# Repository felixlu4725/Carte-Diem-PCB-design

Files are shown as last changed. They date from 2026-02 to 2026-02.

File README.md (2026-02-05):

# Carte Diem — PCB

This directory contains the **custom ESP32-S3-based PCB** designed for the Carte Diem smart shopping cart system.  
The board serves as the central embedded controller, interfacing with all on-cart sensors, peripherals, and the Raspberry Pi.

---

## Overview

The PCB is responsible for:
- Real-time sensor acquisition
- Item verification and cart state monitoring
- Power distribution and regulation
- BLE communication with the Raspberry Pi

It was designed to support **all-day operation**, modular peripherals, and reliable performance in a noisy retail environment.

---

## Manufractured PCB


## Key Features

- **ESP32-S3 MCU**
  - Runs FreeRTOS
  - Handles sensing, control, and BLE communication

- **Peripheral Interfaces**
  - UART: barcode scanner, item RFID, cart-tracking RFID
  - SPI: payment RFID module
  - I²C: IMU, proximity sensor
  - GPIO + ADC: load cells (via HX711)

- **Power Architecture**
  - 12 V input (external battery)
  - On-board buck and LDO regulation
  - Supports 12 V, 9 V, 5 V, 3.3 V, and 1.8 V rails

- **Connectivity**
  - BLE for bidirectional communication with Raspberry Pi
  - Dedicated connectors for modular sensor attachment

---

## Design Notes

- EMI mitigation was required due to proximity of RFID modules and load cells  
- Power paths were designed conservatively to support peak current draw  
- The board went through multiple revisions to resolve rail shorting and voltage tolerance issues  

---

## Schematic

### Top level


### Power Distribution


### Integrated IMU


### Routing


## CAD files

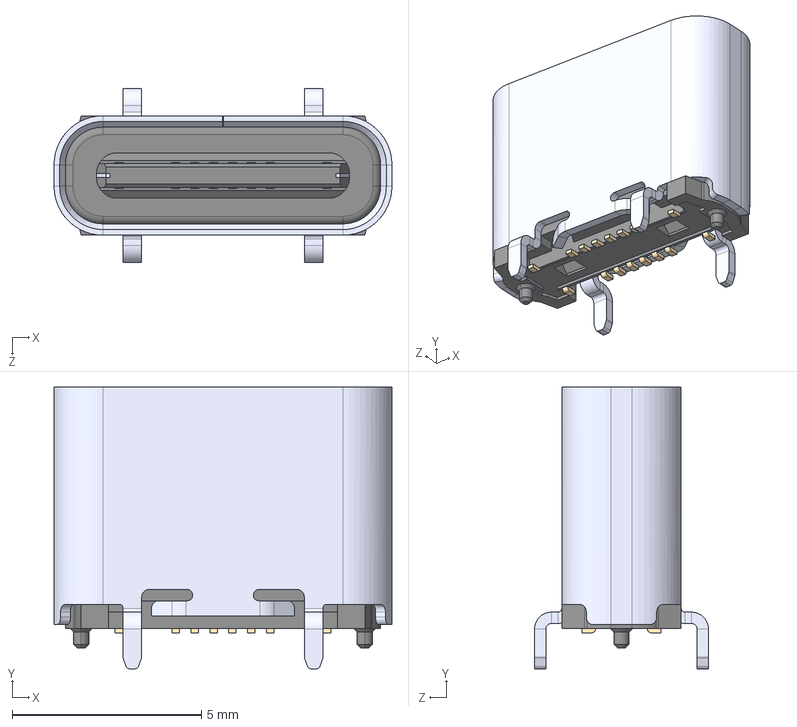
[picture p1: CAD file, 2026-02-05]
Custom_Library/StepFiles/USB4120-03-C_REVA.step
8.94 x 7.45 x 4.60 mm

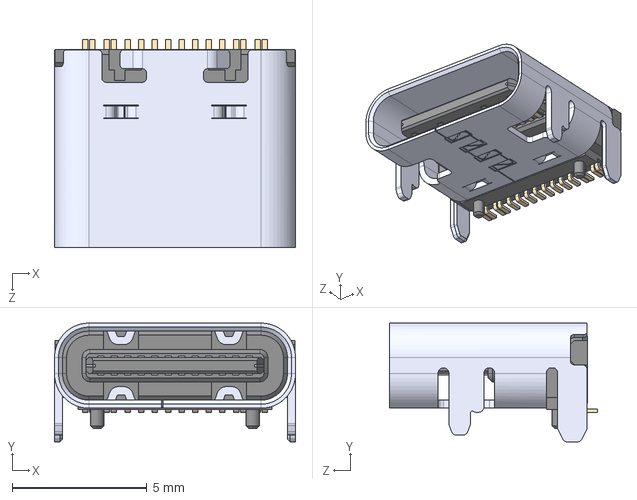
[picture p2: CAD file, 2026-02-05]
Custom_Library/StepFiles/USB4105GFA.step
8.94 x 4.41 x 7.71 mm

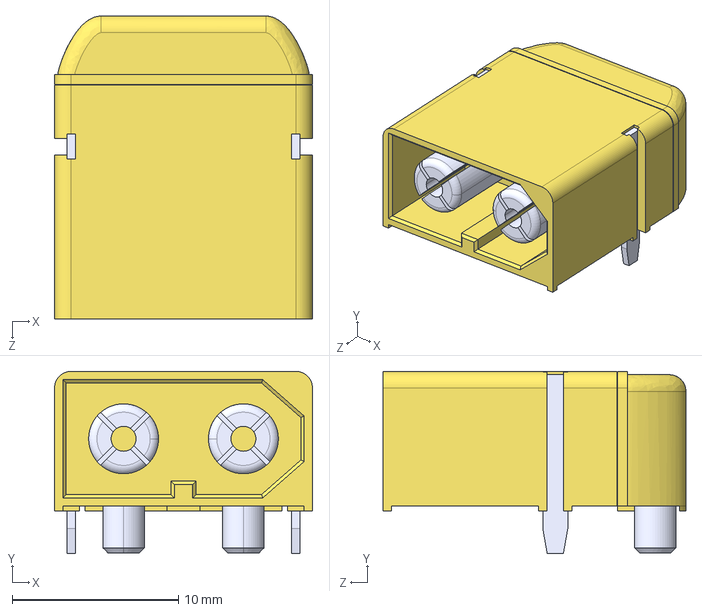
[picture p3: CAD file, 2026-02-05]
Custom_Library/StepFiles/XT60PW-M.step
15.5 x 10.9 x 18.2 mm

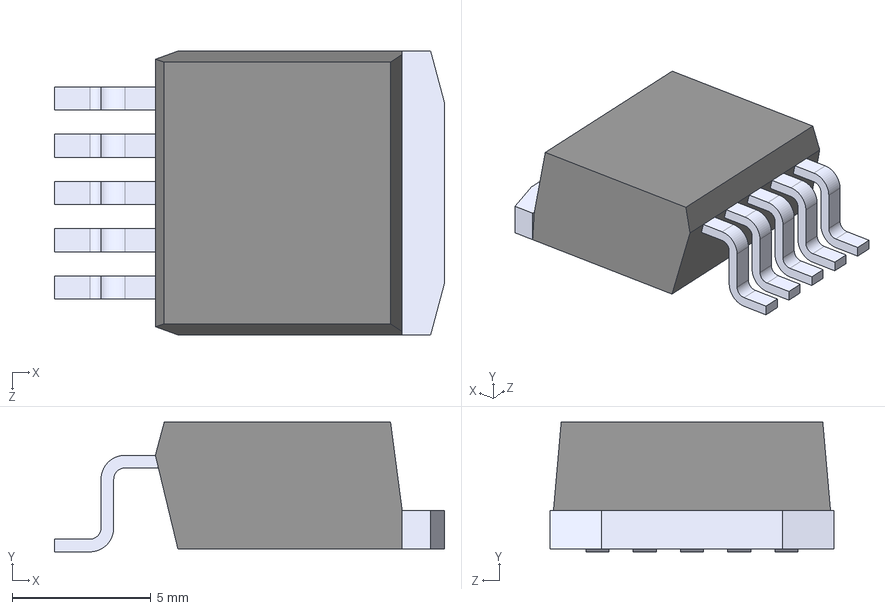
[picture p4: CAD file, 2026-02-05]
Custom_Library/StepFiles/LT1764AEQPBF.step
14.0 x 4.67 x 10.2 mm

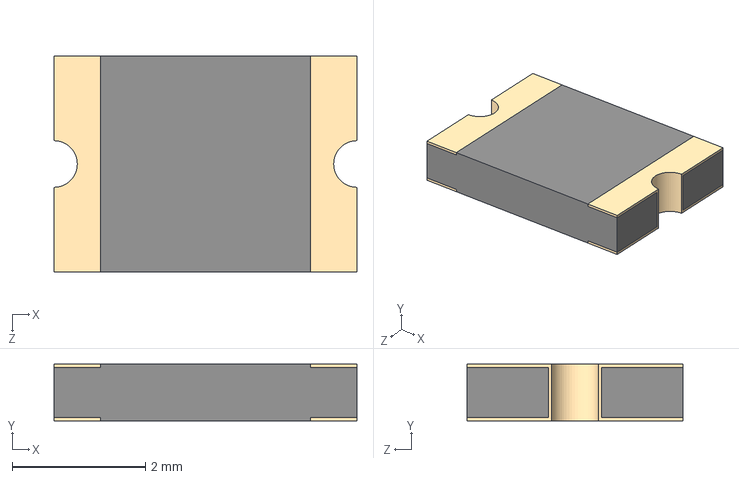
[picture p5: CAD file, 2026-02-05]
Custom_Library/StepFiles/MF-MSMF010-2.step
4.55 x 0.85 x 3.24 mm

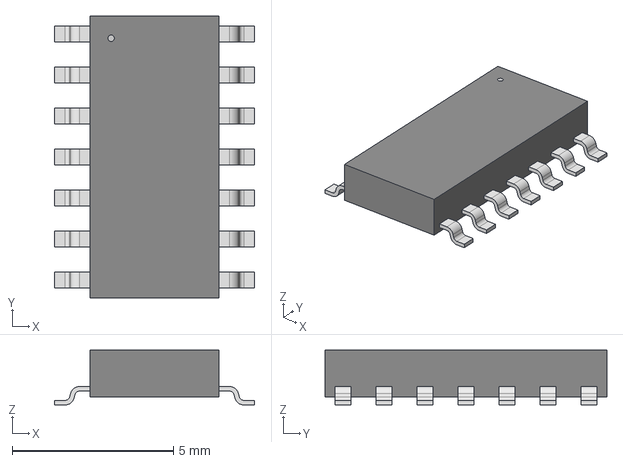
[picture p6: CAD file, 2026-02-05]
Custom_Library/StepFiles/SO14_DIO.step
6.20 x 8.74 x 1.70 mm

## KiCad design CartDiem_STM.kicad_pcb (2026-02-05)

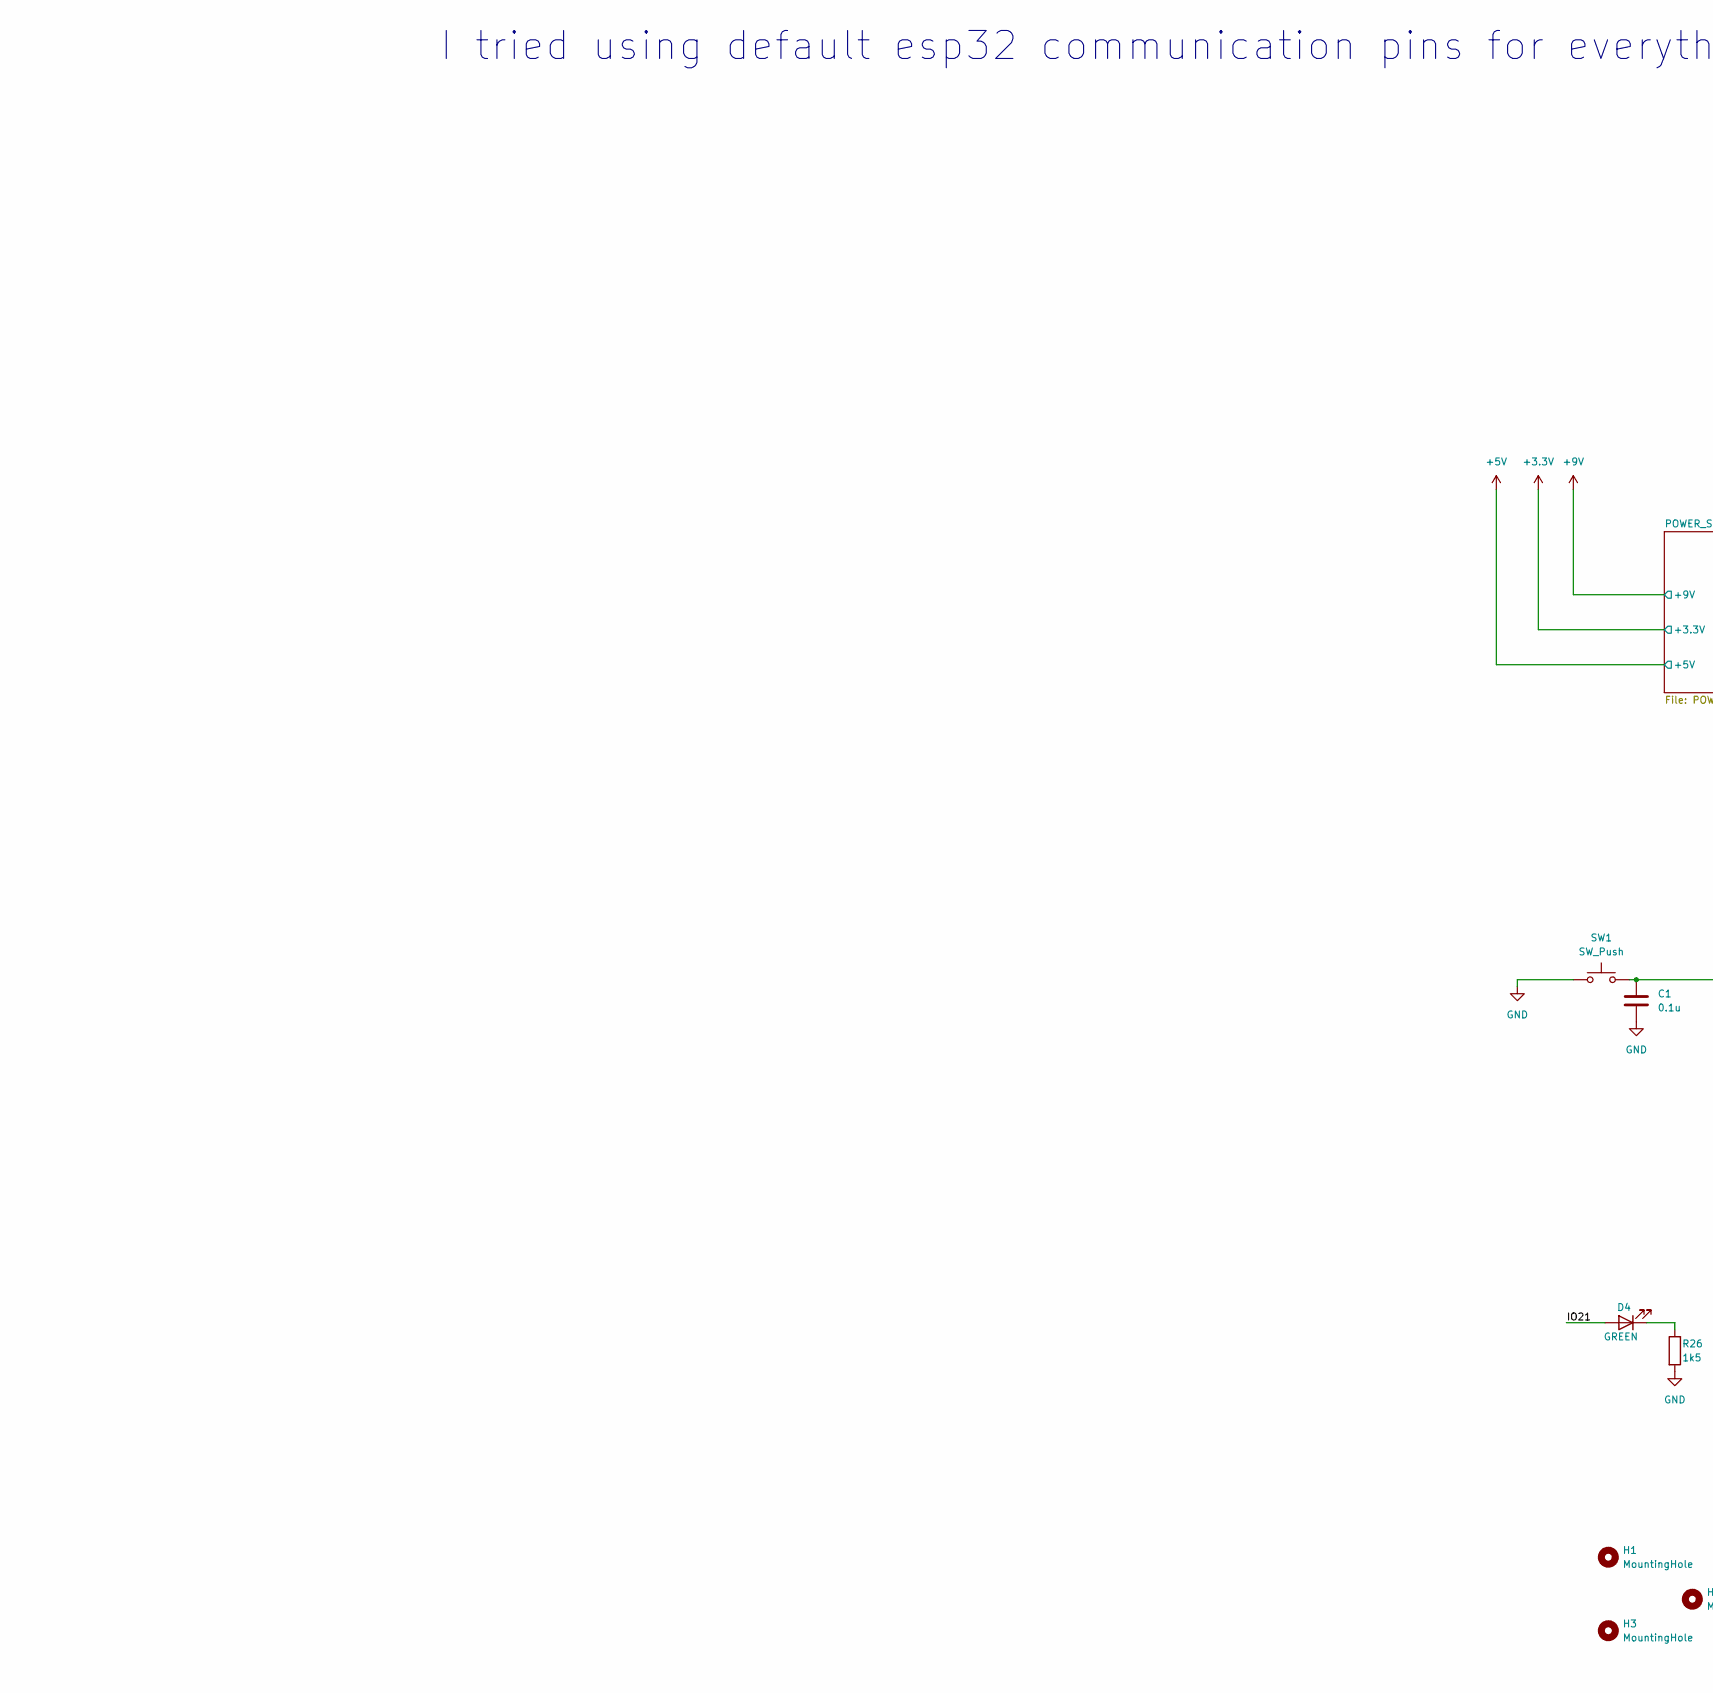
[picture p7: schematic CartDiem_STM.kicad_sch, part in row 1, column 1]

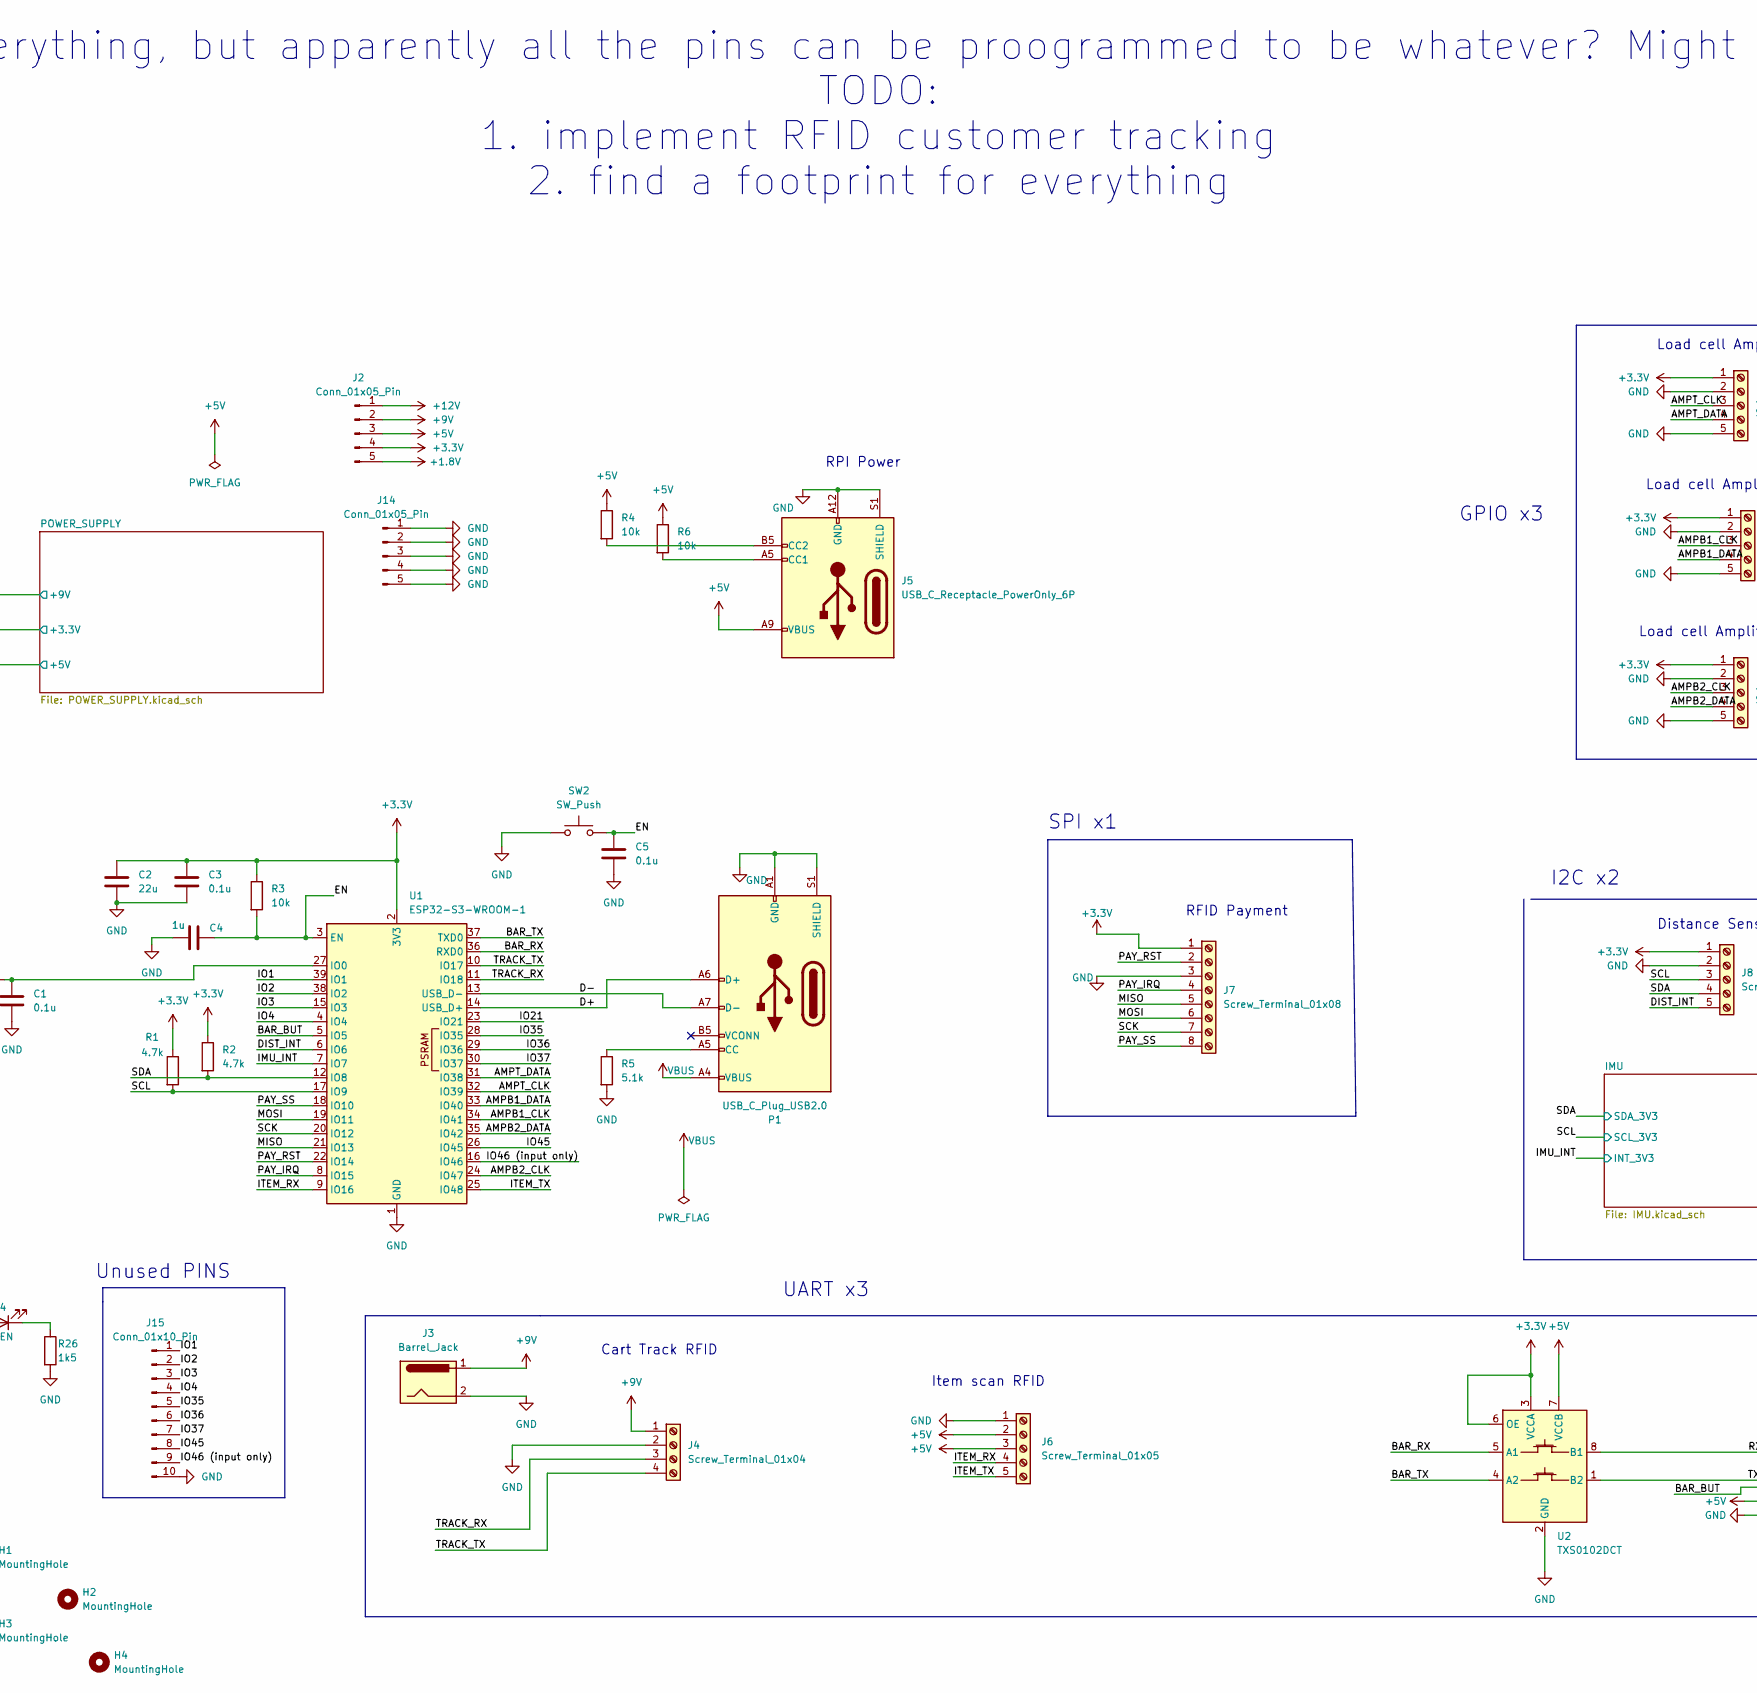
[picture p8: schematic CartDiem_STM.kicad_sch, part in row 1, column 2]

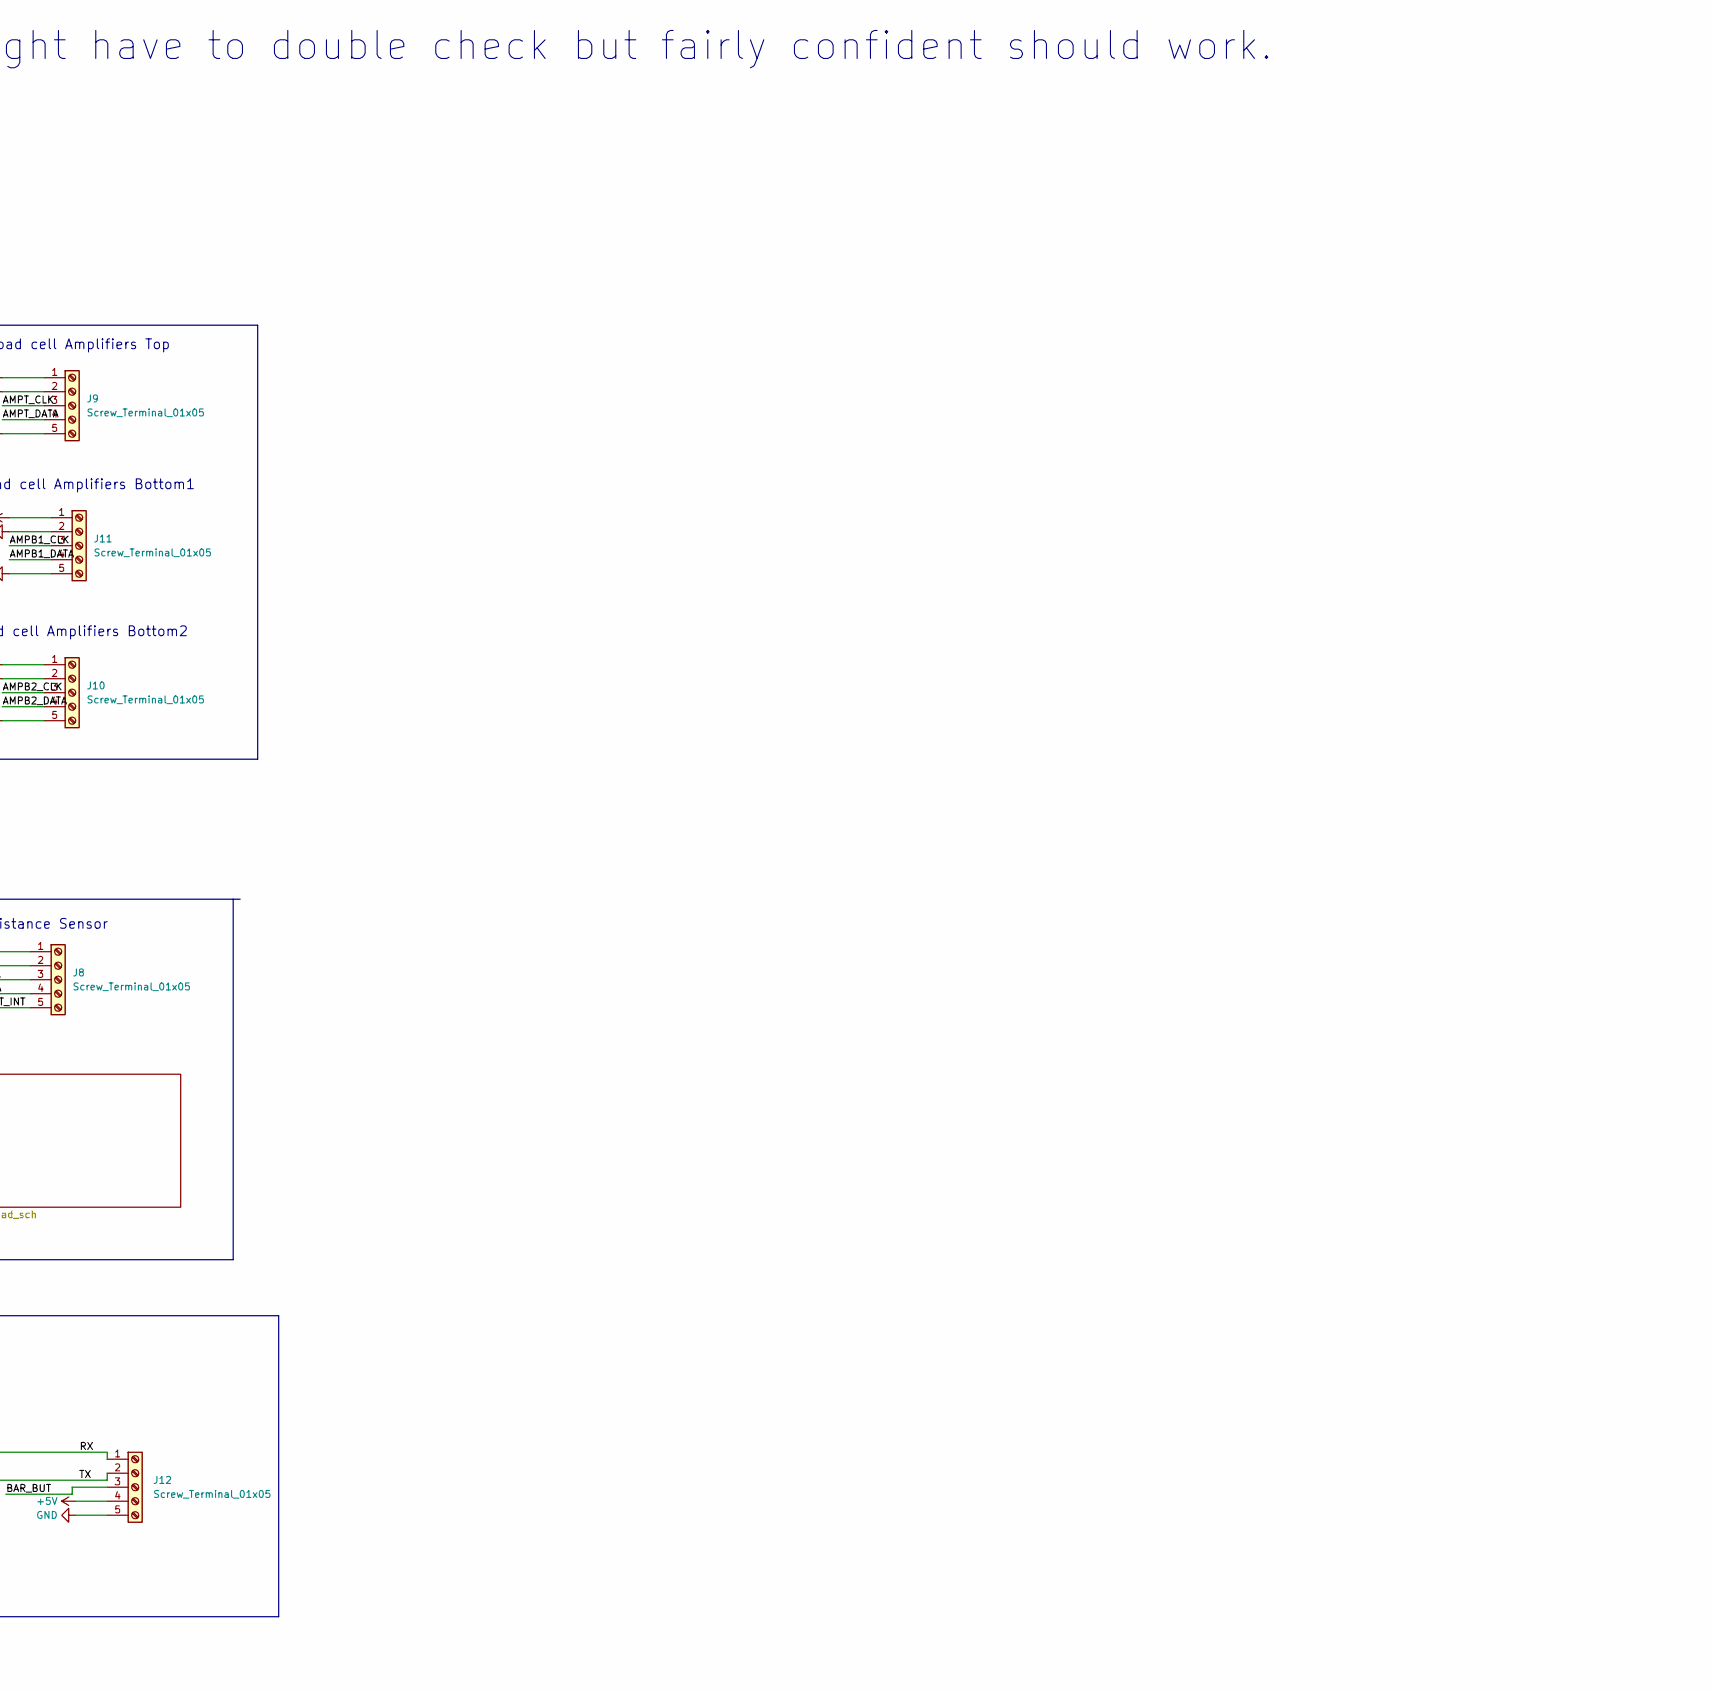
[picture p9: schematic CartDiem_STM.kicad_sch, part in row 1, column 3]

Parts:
C1, C3, C5: 0.1u; C_0603_1608Metric
C2: 22u; C_1210_3225Metric
C4: 1u; C_0603_1608Metric
D4: GREEN; LED_0603_1608Metric
H1, H2, H3, H4: MountingHole; MountingHole_3.2mm_M3
J2, J14: Conn_01x05_Pin; PinHeader_1x05_P2.54mm_Vertical
J3: Barrel_Jack; BarrelJack_CUI_PJ-063AH_Horizontal
J4: Screw_Terminal_01x04; TerminalBlock_Xinya_XY308-2.54-4P_1x04_P2.54mm_Horizontal
J5: USB_C_Receptacle_PowerOnly_6P; USB_C_Receptacle_GCT_USB4125-xx-x-0190_6P_TopMnt_Horizontal
J6, J8, J9, J10, J11, J12: Screw_Terminal_01x05; TerminalBlock_Xinya_XY308-2.54-5P_1x05_P2.54mm_Horizontal
J7: Screw_Terminal_01x08; TerminalBlock_Xinya_XY308-2.54-8P_1x08_P2.54mm_Horizontal
J15: Conn_01x10_Pin; PinHeader_1x10_P2.54mm_Vertical
P1: USB_C_Plug_USB2.0; GCT_USB4120-03-C_REVA
R1, R2: 4.7k; R_0603_1608Metric
R3, R4, R6: 10k; R_0603_1608Metric
R5: 5.1k; R_0603_1608Metric
R26: 1k5; R_0603_1608Metric
SW1, SW2: SW_Push; SW_Push_1P1T_XKB_TS-1187A
U1: ESP32-S3-WROOM-1
U2: TXS0102DCT; SSOP-8_2.95x2.8mm_P0.65mm

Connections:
+1.8V: J2.5; also elsewhere on the board
+3.3V: C2.1, C3.1, J2.4, J7.1, J8.1, J9.1, J10.1, J11.1, R1.1, R2.1, R3.1, U1.2 (3V3), U2.3 (VCCA), U2.6 (OE); also elsewhere on the board
+5V: J2.3, J5.A9 (VBUS), J5.B9 (VBUS), J6.2, J6.3, J12.4, R4.1, R6.1, U2.7 (VCCB); also elsewhere on the board
+9V: J2.2, J3.1, J4.1; also elsewhere on the board
+12V: J2.1; also elsewhere on the board
/AMPB1_CLK: J11.3, U1.34 (IO41)
/AMPB1_DATA: J11.4, U1.33 (IO40)
/AMPB2_CLK: J10.3, U1.24 (IO47)
/AMPB2_DATA: J10.4, U1.35 (IO42)
/AMPT_CLK: J9.3, U1.32 (IO39)
/AMPT_DATA: J9.4, U1.31 (IO38)
/BAR_BUT: J12.3, U1.5 (IO5)
/BAR_RX: U1.36 (RXD0), U2.5 (A1)
/BAR_TX: U1.37 (TXD0), U2.4 (A2)
/D+: P1.A6 (D+), U1.14 (USB_D+)
/D-: P1.A7 (D-), U1.13 (USB_D-)
/DIST_INT: J8.5, U1.6 (IO6)
/EN: C4.2, C5.1, R3.2, SW2.2, U1.3 (EN)
/IMU_INT: U1.7 (IO7); also elsewhere on the board
/IO1: J15.1, U1.39 (IO1)
/IO2: J15.2, U1.38 (IO2)
/IO3: J15.3, U1.15 (IO3)
/IO4: J15.4, U1.4 (IO4)
/IO21: D4.2 (A), U1.23 (IO21)
/IO35: J15.5, U1.28 (IO35)
/IO36: J15.6, U1.29 (IO36)
/IO37: J15.7, U1.30 (IO37)
/IO45: J15.8, U1.26 (IO45)
/IO46 (input only): J15.9, U1.16 (IO46)
/ITEM_RX: J6.4, U1.9 (IO16)
/ITEM_TX: J6.5, U1.25 (IO48)
/MISO: J7.5, U1.21 (IO13)
/MOSI: J7.6, U1.19 (IO11)
/PAY_IRQ: J7.4, U1.8 (IO15)
/PAY_RST: J7.2, U1.22 (IO14)
/PAY_SS: J7.8, U1.18 (IO10)
/RX: J12.1, U2.8 (B1)
/SCK: J7.7, U1.20 (IO12)
/SCL: J8.3, R1.2, U1.17 (IO9); also elsewhere on the board
/SDA: J8.4, R2.2, U1.12 (IO8); also elsewhere on the board
/TRACK_RX: J4.3, U1.11 (IO18)
/TRACK_TX: J4.4, U1.10 (IO17)
/TX: J12.2, U2.1 (B2)
GND: C1.2, C2.2, C3.2, C4.1, C5.2, J3.2, J4.2, J5.A12 (GND), J5.B12 (GND), J5.S1 (SHIELD), J6.1, J7.3, J8.2, J9.2, J9.5, J10.2, J10.5, J11.2, J11.5, J12.5, J14.1, J14.2, J14.3, J14.4, J14.5, J15.10, P1.A1 (GND), P1.A12 (GND), P1.B1 (GND), P1.B12 (GND), P1.S1 (SHIELD), R5.2, R26.2, SW1.1, SW2.1, U1.1 (GND), U1.40 (GND), U1.41 (GND), U2.2 (GND); also elsewhere on the board
unnamed: D4.1 (K), R26.1
unnamed: J5.A5 (CC1), R6.2
unnamed: J5.B5 (CC2), R4.2
unnamed: P1.A5 (CC), R5.1
unnamed: C1.1, SW1.2, U1.27 (IO0)
VBUS: P1.A4 (VBUS), P1.A9 (VBUS), P1.B4 (VBUS), P1.B9 (VBUS); also elsewhere on the board

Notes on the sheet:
Item scan RFID
Unused PINS
Load cell Amplifiers Bottom2
RFID Payment
Cart Track RFID
Distance Sensor
SPI x1
Load cell Amplifiers Bottom1
UART x3
I tried using default esp32 communication pins for everything, but apparently all the pins can be proogrammed to be whatever? Might have to double check but fairly confident should work. TODO: 1. implement RFID customer tracking 2. find a footprint for everything
Load cell Amplifiers Top
GPIO x3
RPI Power
I2C x2

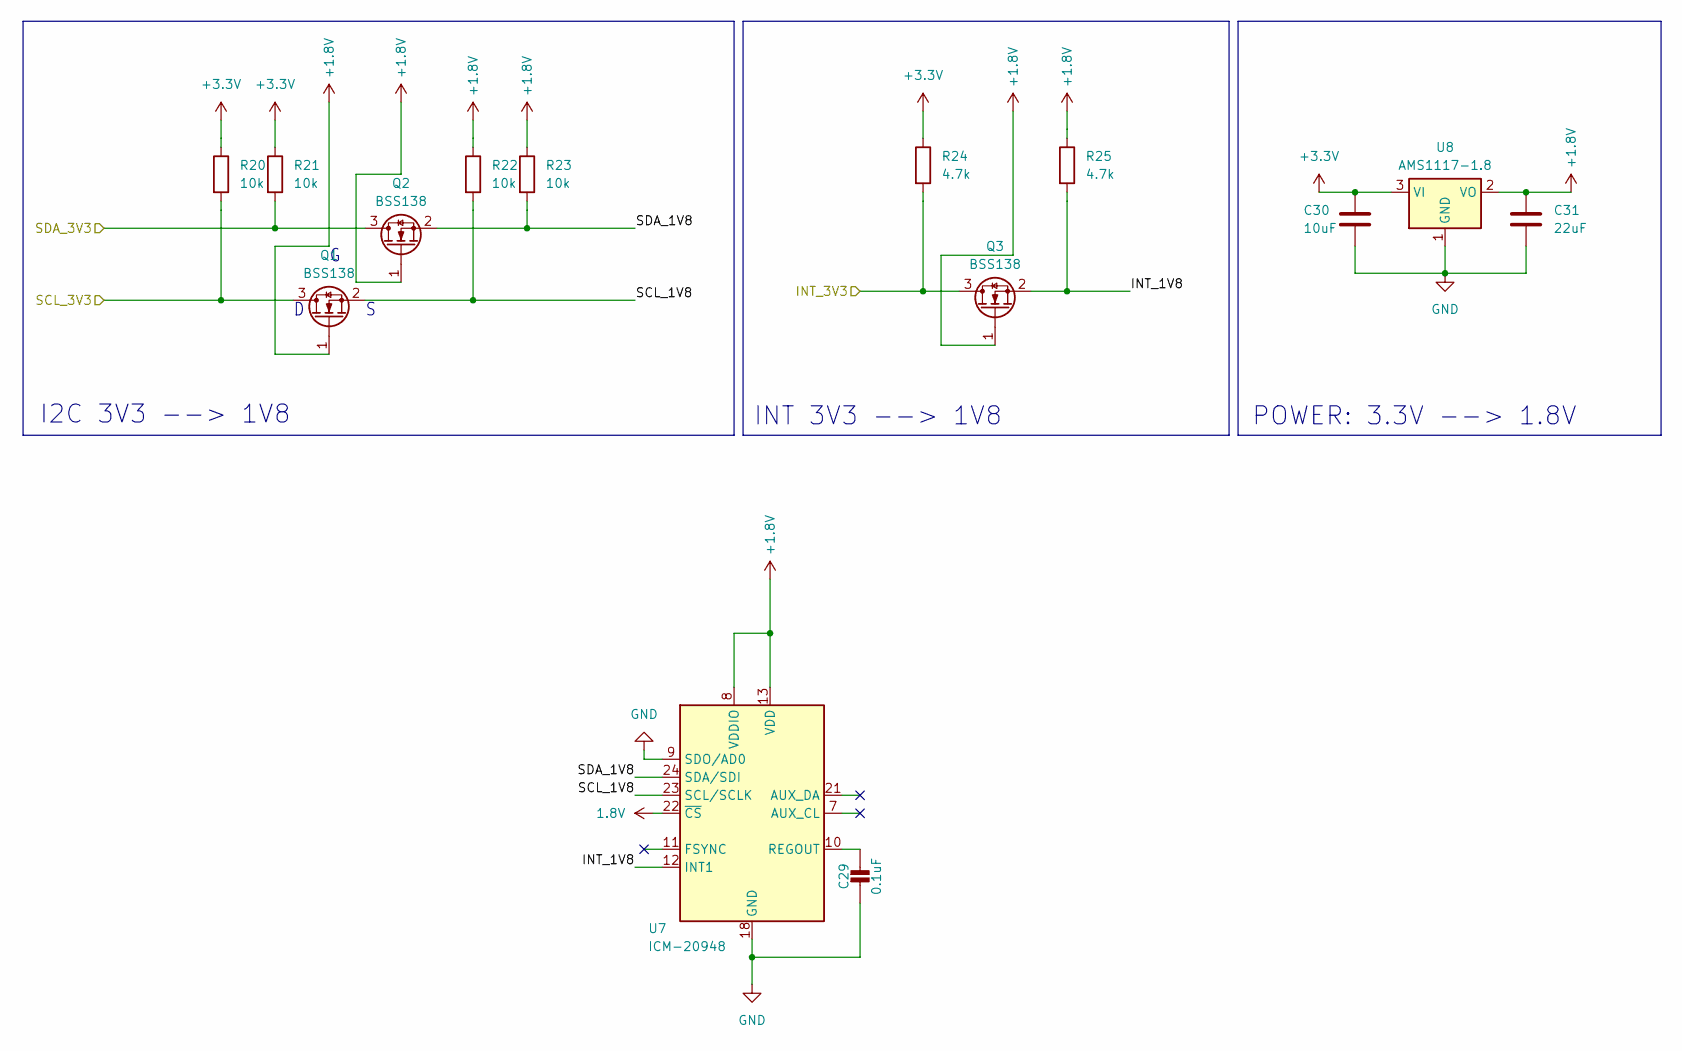
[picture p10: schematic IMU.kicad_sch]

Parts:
C29: 0.1uF; C_0603_1608Metric
C30: 10uF; C_0805_2012Metric
C31: 22uF; C_1210_3225Metric
Q1, Q2, Q3: BSS138; SOT-23
R20, R21, R22, R23: 10k; R_0603_1608Metric
R24, R25: 4.7k; R_0603_1608Metric
U7: ICM-20948; InvenSense_QFN-24_3x3mm_P0.4mm
U8: AMS1117-1.8; SOT-223-3_TabPin2

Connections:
1.8V: U7.22 (~CS)
+1.8V: C31.1, Q1.1 (G), Q2.1 (G), Q3.1 (G), R22.1, R23.1, R25.1, U7.8 (VDDIO), U7.13 (VDD), U8.2 (VO); also elsewhere on the board
+3.3V: C30.2, R20.1, R21.1, R24.1, U8.3 (VI); also elsewhere on the board
/IMU/INT_1V8: Q3.2 (S), R25.2, U7.12 (INT1)
/IMU/SCL_1V8: Q1.2 (S), R22.2, U7.23 (SCL/SCLK)
/IMU/SDA_1V8: Q2.2 (S), R23.2, U7.24 (SDA/SDI)
/IMU_INT: Q3.3 (D), R24.2; also elsewhere on the board
/SCL: Q1.3 (D), R20.2; also elsewhere on the board
/SDA: Q2.3 (D), R21.2; also elsewhere on the board
GND: C29.2, C30.1, C31.2, U7.9 (SDO/AD0), U7.18 (GND), U7.20 (GND), U8.1 (GND); also elsewhere on the board
unnamed: C29.1, U7.10 (REGOUT)

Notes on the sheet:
I2C 3V3 --> 1V8
INT 3V3 --> 1V8
POWER: 3.3V --> 1.8V

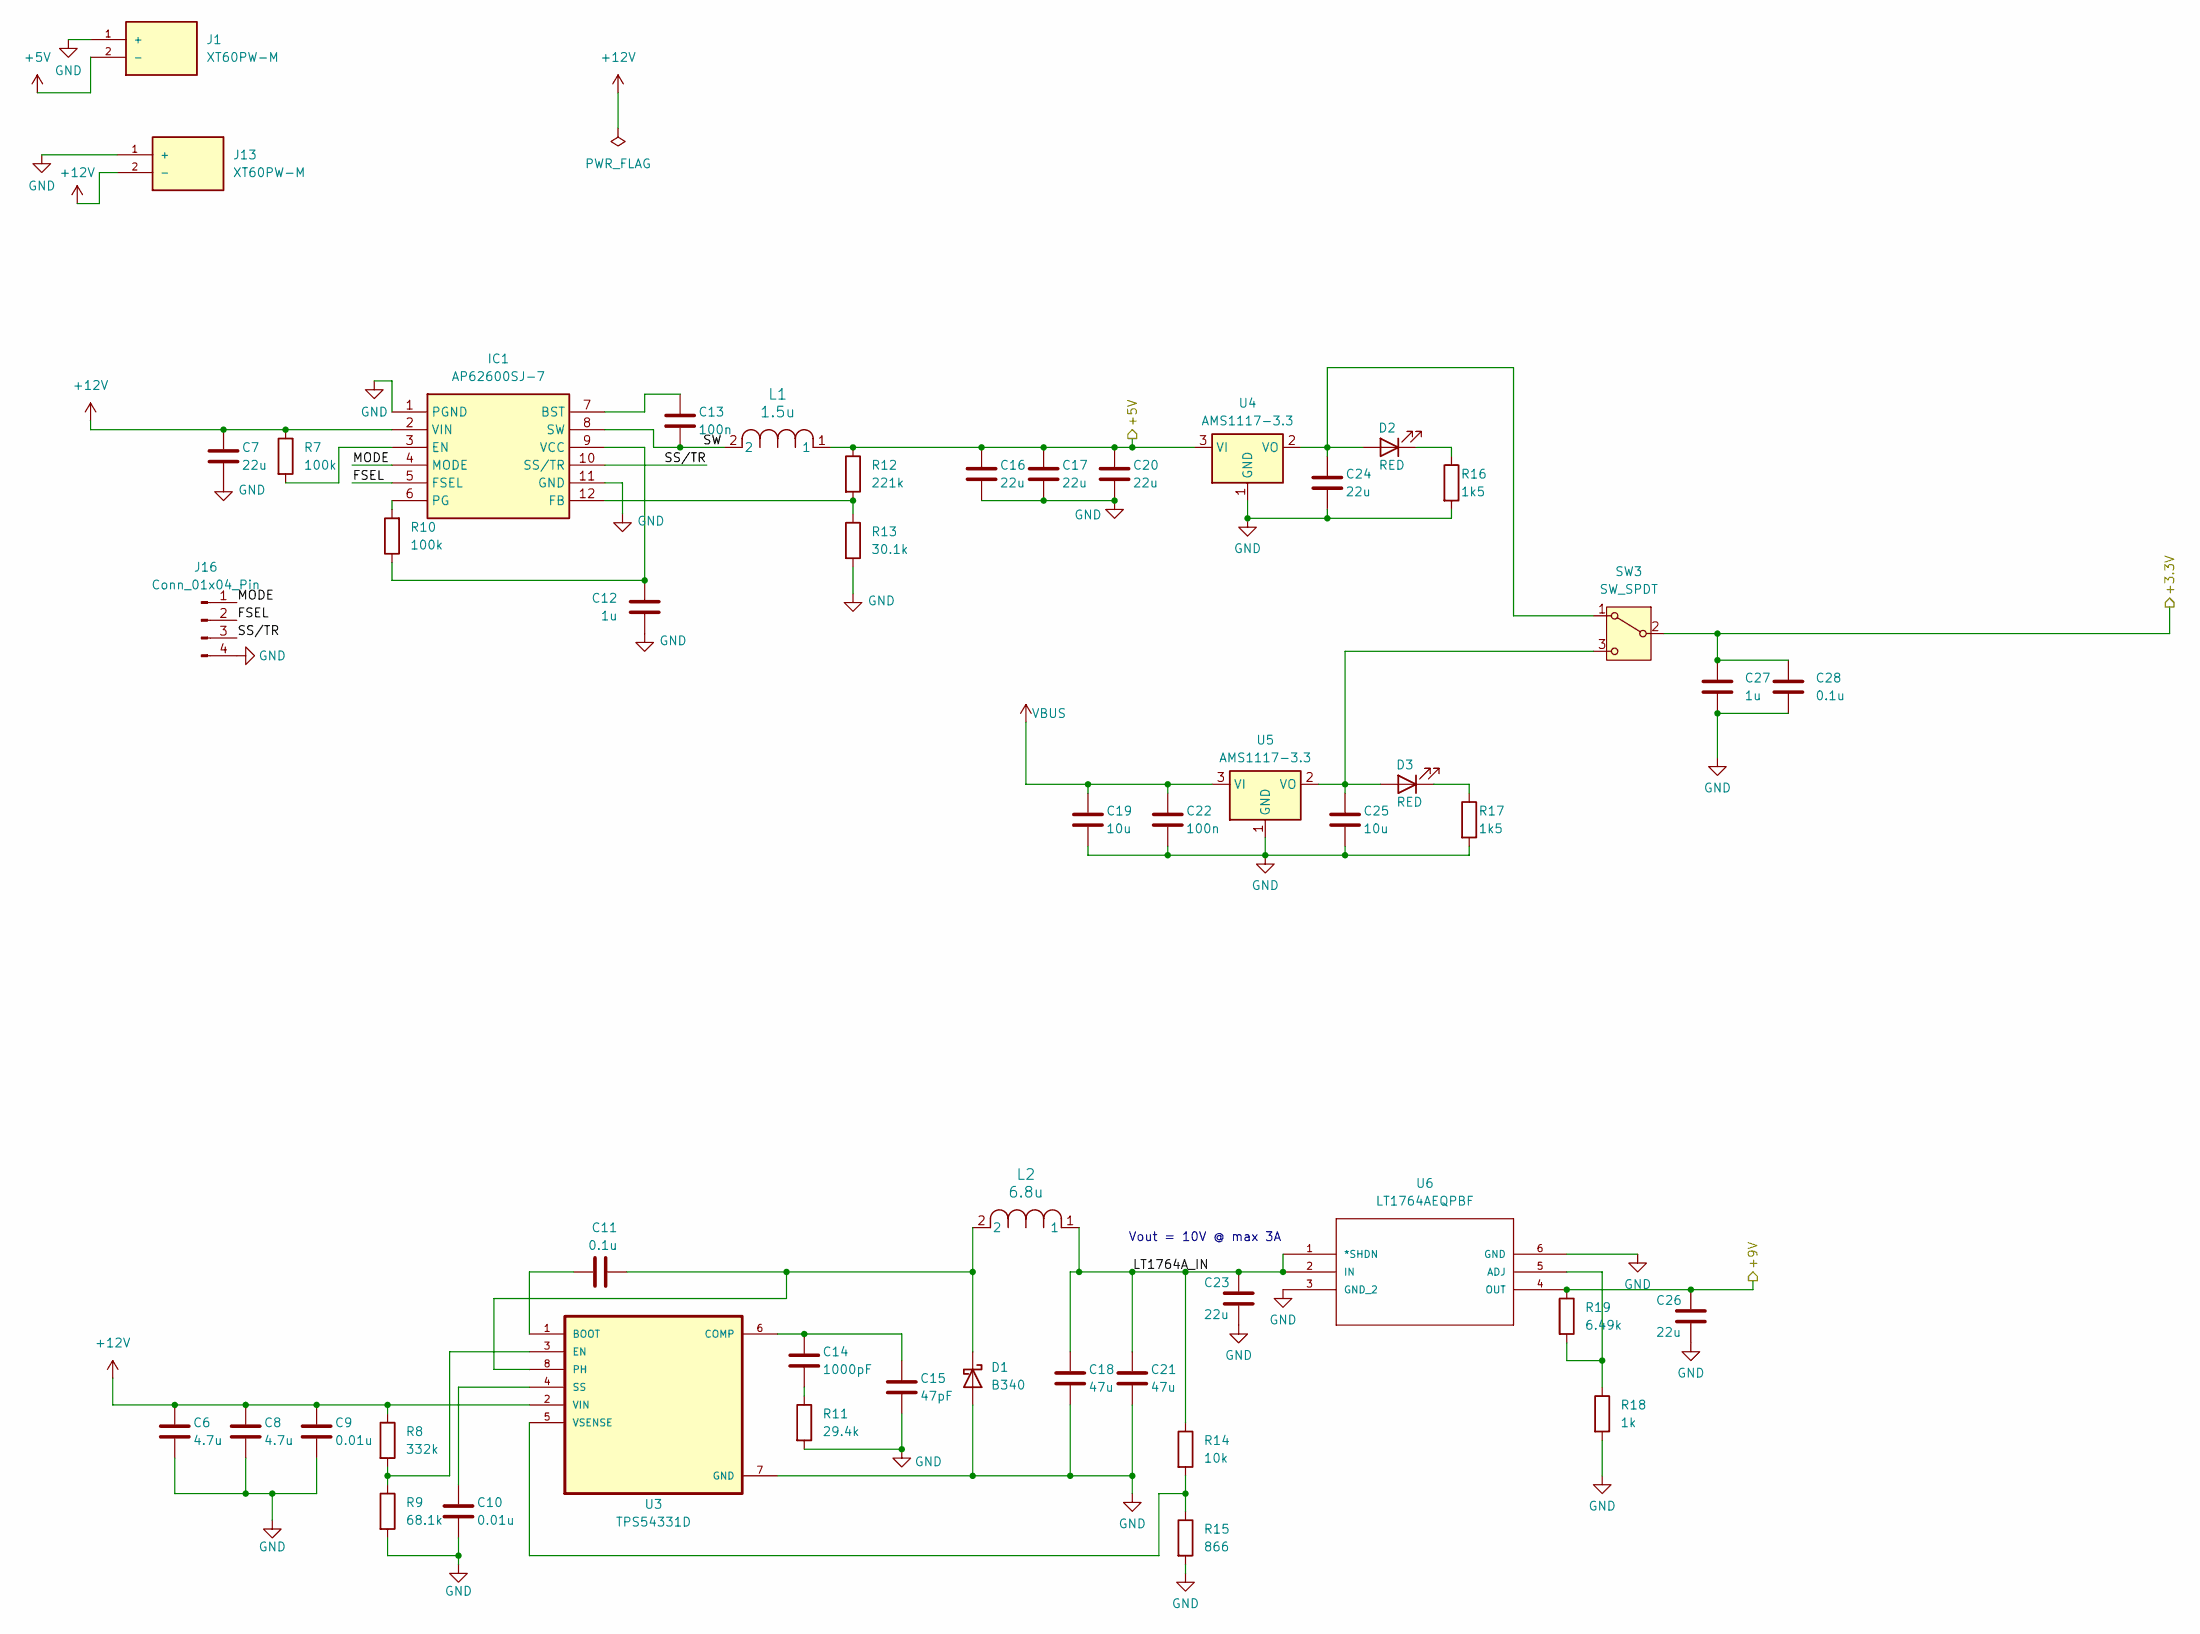
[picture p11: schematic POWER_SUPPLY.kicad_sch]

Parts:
C6, C8: 4.7u; C_0805_2012Metric
C7, C16, C17, C20: 22u; C_1210_3225Metric
C9, C10: 0.01u; C_0603_1608Metric
C11, C28: 0.1u; C_0603_1608Metric
C12, C27: 1u; C_0603_1608Metric
C13, C22: 100n; C_0805_2012Metric
C14: 1000pF; C_0603_1608Metric
C15: 47pF; C_0603_1608Metric
C18, C21: 47u; C_1210_3225Metric
C19, C25: 10u; C_0805_2012Metric
C23, C26: 22u; C_1206_3216Metric
C24: 22u; C_0805_2012Metric
D1: B340; D_SMC
D2, D3: RED; LED_0603_1608Metric
IC1: AP62600SJ-7; AP62600SJ7; Manufacturer_Part_Number AP62600SJ-7; Mouser Part Number 621-AP62600SJ-7
J1, J13: XT60PW-M; AMASS_XT60IPW-M_1x03_P7.20mm_Horizontal; PARTREV V1.2
J16: Conn_01x04_Pin; PinSocket_1x04_P2.54mm_Vertical
L1: 1.5u; L_Bourns_SRP6060FA
L2: 6.8u; L_Bourns_SRP6060FA
R7: 100k; R_0805_2012Metric
R8: 332k; R_0805_2012Metric
R9: 68.1k; R_0805_2012Metric
R10: 100k; R_0603_1608Metric
R11: 29.4k; R_0603_1608Metric
R12: 221k; R_0603_1608Metric
R13: 30.1k; R_0603_1608Metric
R14: 10k; R_0603_1608Metric
R15: 866; R_0603_1608Metric
R16, R17: 1k5; R_0603_1608Metric
R18: 1k; R_0603_1608Metric
R19: 6.49k; R_0603_1608Metric
SW3: SW_SPDT; SW_SPDT_PCM12
U3: TPS54331D; SOIC127P599X175-8N
U4, U5: AMS1117-3.3; SOT-223-3_TabPin2
U6: LT1764AEQPBF; DDPAK-5_Q; MANUFACTURER_PART_NUMBER LT1764AEQ#PBF; DIGIKEY_PART_NUMBER LT1764AEQ#PBFND

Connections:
+3.3V: C27.1, C28.1, SW3.2 (B); also elsewhere on the board
+5V: C16.1, C17.1, C20.1, J1.2 (-), L1.1, R12.1, U4.3 (VI); also elsewhere on the board
+9V: C26.1, R19.1, U6.4 (OUT); also elsewhere on the board
+12V: C6.1, C7.1, C8.1, C9.1, IC1.2 (VIN), J13.2 (-), R7.1, R8.1, U3.2 (VIN); also elsewhere on the board
/POWER_SUPPLY/FSEL: IC1.5 (FSEL), J16.2
/POWER_SUPPLY/LT1764A_IN: C18.1, C21.1, C23.1, L2.1, R14.1, U6.1 (*SHDN), U6.2 (IN)
/POWER_SUPPLY/MODE: IC1.4 (MODE), J16.1
/POWER_SUPPLY/SS/TR: IC1.10 (SS/TR), J16.3
/POWER_SUPPLY/SW: C13.2, IC1.8 (SW), L1.2
GND: C6.2, C7.2, C8.2, C9.2, C10.2, C12.1, C15.2, C16.2, C17.2, C18.2, C19.2, C20.2, C21.2, C22.2, C23.2, C24.2, C25.2, C26.2, C27.2, C28.2, D1.2 (A), IC1.1 (PGND), IC1.11 (GND), J1.1 (+), J13.1 (+), J16.4, R9.2, R11.2, R13.2, R15.2, R16.2, R17.2, R18.2, U3.7 (GND), U4.1 (GND), U5.1 (GND), U6.3 (GND_2), U6.6 (GND); also elsewhere on the board
unnamed: C14.2, R11.1
unnamed: C11.2, D1.1 (K), L2.2, U3.8 (PH)
unnamed: C24.1, D2.2 (A), SW3.1 (A), U4.2 (VO)
unnamed: D2.1 (K), R16.1
unnamed: C25.1, D3.2 (A), SW3.3 (C), U5.2 (VO)
unnamed: D3.1 (K), R17.1
unnamed: C13.1, IC1.7 (BST)
unnamed: IC1.3 (EN), R7.2
unnamed: IC1.12 (FB), R12.2, R13.1
unnamed: IC1.6 (PG), R10.2
unnamed: C12.2, IC1.9 (VCC), R10.1
unnamed: C11.1, U3.1 (BOOT)
unnamed: C14.1, C15.1, U3.6 (COMP)
unnamed: R8.2, R9.1, U3.3 (EN)
unnamed: C10.1, U3.4 (SS)
unnamed: R14.2, R15.1, U3.5 (VSENSE)
unnamed: R18.1, R19.2, U6.5 (ADJ)
VBUS: C19.1, C22.1, U5.3 (VI); also elsewhere on the board

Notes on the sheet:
Vout = 10V @ max 3A

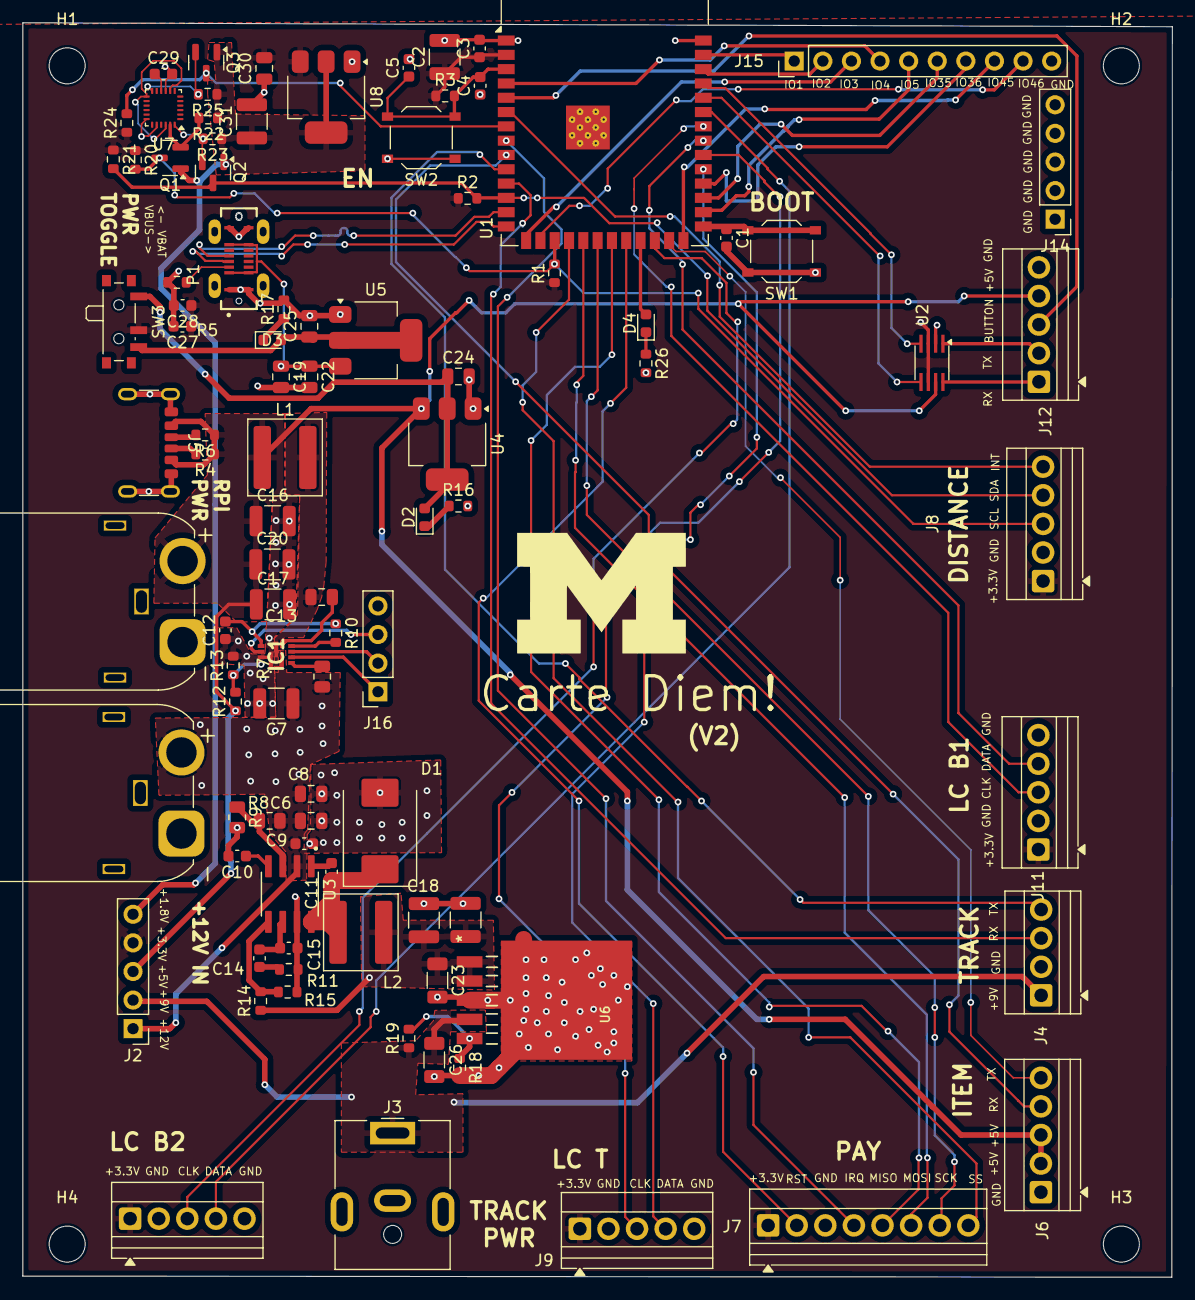
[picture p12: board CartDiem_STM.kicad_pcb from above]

Board: 2 copper layers, 102.1 x 111.4 mm, 99 parts (0 on the bottom side), 76 nets.

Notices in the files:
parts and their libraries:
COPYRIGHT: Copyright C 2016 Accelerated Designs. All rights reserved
